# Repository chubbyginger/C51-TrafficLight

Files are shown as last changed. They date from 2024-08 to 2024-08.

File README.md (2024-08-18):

# C51-TrafficLight
8051红绿灯demo，有行人过街按钮功能

## 硬件部分
主控MCU为STC89C52，为了方便直接买了核心板（Fos44）

单片机IO口全部引出，板子可兼做8051实验板。全过孔，新手可焊。

板上资源：STC89C52单片机一片，一位数码管一个，数码管译码器74LS48一片，红灯绿灯黄灯LED各两个，按钮两个（接int0和int1，可以进行中断实验），74LS174 D触发器2片12个（4个接译码器，2个空着没用，6个接在单片机io口上）。

PCB是嘉立创eda画的，有点不习惯，以前一直用KiCad。



下面这张板子是第一版的，漏加了三个去耦电容，三个上下拉电阻，两个按键的丝印画反了，另外RESET的上下拉接反了所以这一版RESET键不起作用。当时课题组急着让我交PCB好去打板，所以有的地方没仔细看就打了。上述问题第二版已修复。另外，旧版的LED灯有点暗，第二版将LED灯限流电阻改小了，会亮一些。但要注意第二版还没验证，不保证一定能用。



成品如下



## 软件部分
逻辑：开机默认显示车行道绿灯，人行道红灯。按下P3.2按钮，开始倒计时，倒计时结束后车行道变黄灯→红灯，人行道变绿灯，开始倒计时，倒计时结束后人行道变红灯，车行道变绿灯，回到默认状态。

FSM实现，大概两百行，抄了一些STC的例程。IDE用的~~礦ision~~ Keil5

代码中有一些UART相关的部分，仅供调试用，是可以删除的。

配套有一个proteus文件，可以用于模拟、调试。

## 制作方法
1. 硬件：数码管一定要最后一个焊接。U2、D5、P0~P4、J4~J5、R8、K2和红绿灯无关可以不装。
   
   注意！！核心板一定要USB口朝上，P4口朝下！装错了无法使用。
2. 软件：用STC ISP下载hex文件即可。核心板自带CH340，所以可以不用板上的UART接口下载。下载时，先点击ISP软件编程按钮，然后按一下板子上的RESET键（或者把核心板上电源开关关掉再打开一次）即可开始下载。

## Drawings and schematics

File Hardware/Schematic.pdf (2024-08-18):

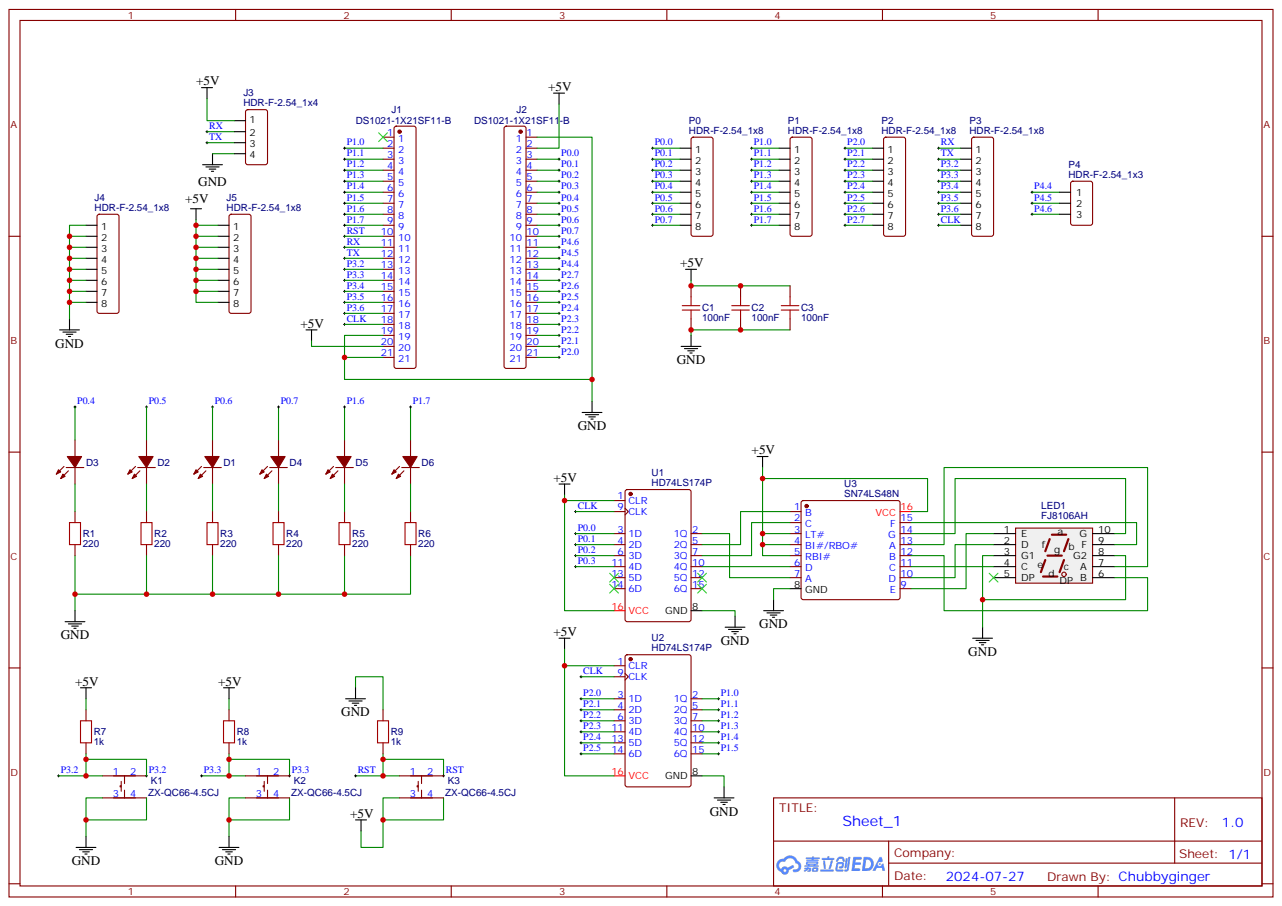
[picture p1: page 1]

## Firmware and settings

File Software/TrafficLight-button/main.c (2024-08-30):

#include <reg52.h>
#include <intrins.h>
#include <stdio.h>
#include "STCUART.h"
#include "main.h"
#include "Key.h"
#include "hwinit.h"

unsigned char state = 0;
/*
	State0: 车绿灯，行人红灯
	State1: 车倒计时绿灯，行人红灯
	State2: 车黄灯，行人红灯
	State3: 车红灯，行人红灯
	State4: 车红灯，行人倒计时绿灯
	State5: 车红灯，行人红灯
	然后回到State0
*/
unsigned char Tcnt = 20;
unsigned char Icnt = 20;

void Delay1ms(int t)		//@11.0592MHz
{
	int k = 0;
	for (k = 0; k < t; k++) 
	{
		unsigned char i, j;
		_nop_();
		i = 2;
		j = 199;
		do {
			while (--j);
		}
		while (--i);
	}
}

void switchState(int buttonState) {
	if (state == 0 && buttonState == 1) {
		state = 1;
		SendString("Switching to state 1\r\n");
		TR0 = 1;
	}
}

void clearScreen() {
	DCLK = 1;
	Display0 = 1;
	Display1 = 1;
	Display2 = 1;
	Display3 = 1;
	DCLK = 0;
}

void Timer0_ISR() interrupt 1 using 1 {
	TH0 = (65536 - 50*1000)/256;
	TL0 = (65536 - 50*1000)%256;
	if (Icnt > 0) {
		Icnt--;
	} else { // Tcnt=0时切换模式
		Icnt = 20;
		if (Tcnt > 0) {
			Tcnt--;
		} else {
			TR0 = 0;
			switch (state) {
				case 1:
					SendString("Switching to state 2\r\n");
					state = 2;
					Tcnt = 3;
					TR0 = 1;
					break;
				case 2:
					SendString("Switching to state 3\r\n");
					state = 3;
					Tcnt = 3;
					TR0 = 1;
					break;
				case 3:
					SendString("Switching to state 4\r\n");
					state = 4;
					Tcnt = 20;
					TR0 = 1;
					break;
				case 4:
					SendString("Switching to state 5\r\n");
					state = 5;
					Tcnt = 3;
					TR0 = 1;
					break;
				case 5:
					SendString("Switching to state 0\r\n");
					state = 0;
					Tcnt = 20;
					break;
				default:
					SendString("FSM internal error");
					break;
			}
		}
	}
}

void main() {
	UartInit();
	SendString("UART initialization OK\r\n");
	Timer0Init();
	SendString("Timer0 initialization OK\r\n");
	DisplayInit();
	SendString("Display initialization OK\r\n");
	
	while (1)
	{
		switchState(ReadKey());
		if (state == 0)
		{
			LED1_R = 0;
			LED1_Y = 0;
			LED1_G = 1;
			LED2_R = 1;
			LED2_Y = 0;
			LED2_G = 0;
		}
		else if (state == 1)
		{
			LED1_R = 0;
			LED1_Y = 0;
			LED1_G = 1;
			LED2_R = 1;
			LED2_Y = 0;
			LED2_G = 0;
			if (Tcnt <= 9) {
				DCLK = 1;
				Display0 = Tcnt%2;	
				Display1 = (Tcnt/2)%2;
				Display2 = (Tcnt/4)%2;
				Display3 = (Tcnt/8)%2;
				DCLK = 0;
			} else {
				DCLK = 1;
				Display0 = 1;
				Display1 = 1;
				Display2 = 1;
				Display3 = 1;
				DCLK = 0;
			}
		}
		else if (state == 2)
		{
			LED1_R = 0;
			LED1_Y = 1;
			LED1_G = 0;
			LED2_R = 1;
			LED2_Y = 0;
			LED2_G = 0;
			clearScreen();
		}
		else if (state == 3)
		{
			LED1_R = 1;
			LED1_Y = 0;
			LED1_G = 0;
			LED2_R = 1;
			LED2_Y = 0;
			LED2_G = 0;
			clearScreen();
		}
		else if (state == 4)
		{
			LED1_R = 1;
			LED1_Y = 0;
			LED1_G = 0;
			LED2_R = 0;
			LED2_Y = 0;
			LED2_G = 1;
			if (Tcnt <= 9) {
				DCLK = 1;
				Display0 = Tcnt%2;	
				Display1 = (Tcnt/2)%2;
				Display2 = (Tcnt/4)%2;
				Display3 = (Tcnt/8)%2;
				DCLK = 0;
			} else {
				DCLK = 1;
				Display0 = 1;
				Display1 = 1;
				Display2 = 1;
				Display3 = 1;
				DCLK = 0;
			}
		}
		else if (state == 5)
		{
			LED1_R = 1;
			LED1_Y = 0;
			LED1_G = 0;
			LED2_R = 1;
			LED2_Y = 0;
			LED2_G = 0;
			clearScreen();
		}
		else
		{
			LED1_R = 0;
			LED1_Y = 0;
			LED1_G = 1;
			LED2_R = 1;
			LED2_Y = 0;
			LED2_G = 0;
			clearScreen();
		}
		Delay1ms(10);
	}
}

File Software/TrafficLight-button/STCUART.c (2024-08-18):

/*------------------------------------------------------------------*/
/* --- STC MCU Limited ---------------------------------------------*/
/* --- STC89-90xx Series MCU UART (8-bit/9-bit)Demo ----------------*/
/* --- Mobile: (86)13922805190 -------------------------------------*/
/* --- Fax: 86-0513-55012956,55012947,55012969 ---------------------*/
/* --- Tel: 86-0513-55012928,55012929,55012966----------------------*/
/* --- Web: www.STCMCU.com -----------------------------------------*/
/* --- Web: www.GXWMCU.com -----------------------------------------*/
/* If you want to use the program or the program referenced in the  */
/* article, please specify in which data and procedures from STC    */
/*------------------------------------------------------------------*/

#include "reg51.h"
#include "intrins.h"
#include "STCUART.h"
#include "main.h"

bit busy;

void UartInit()
{
    SCON = 0x50;            //8-bit variable UART
    TMOD = 0x20;            //Set Timer1 as 8-bit auto reload mode
    TH1 = -(FOSC/12/32/BAUD); //Set auto-reload vaule
		TL1 = -(FOSC/12/32/BAUD);
		ET1 = 0;
    TR1 = 1;                //Timer1 start run
}

/*----------------------------
Send a byte data to UART
Input: dat (data to be sent)
Output:None
----------------------------*/
void SendData(BYTE dat)
{
    SBUF = dat;             //Send data to UART buffer
		while (!TI);
		TI = 0;
}

/*----------------------------
Send a string to UART
Input: s (address of string)
Output:None
----------------------------*/
void SendString(char *s)
{
    while (*s != '\0')              //Check the end of the string
    {
        SendData(*s);     //Send current char
			  s++;
    }
}

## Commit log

2024-08-18 first upload
    [Drill_PTH_Through.DRL, Drill_PTH_Through_Via.DRL, Gerber_BoardOutlineLayer.GKO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]
2024-08-30 Software: update to 2.0, fixed display bug
    [main.c]
